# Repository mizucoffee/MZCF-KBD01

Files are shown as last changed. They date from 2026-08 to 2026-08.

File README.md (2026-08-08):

# MZCF-KBD01 V1 Rev.2

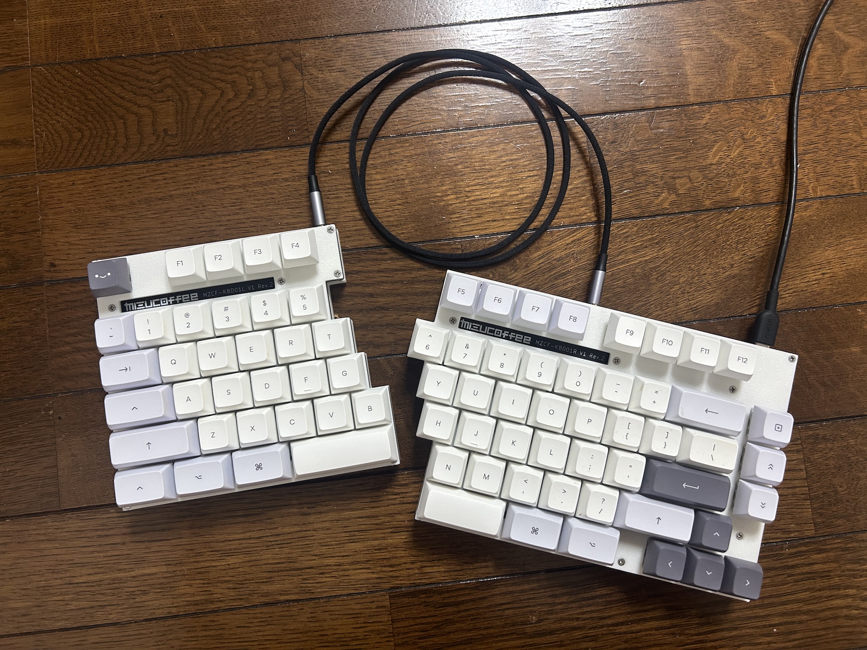
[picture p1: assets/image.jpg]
キーボード写真


RP2040-Zero を搭載した分割キーボード。レイアウトは [ergogen](https://github.com/ergogen/ergogen) で生成し、KiCad 10 で設計しています。

## 構成

| パス | 内容 |
|---|---|
| `ergogen/` | ergogen 実行用ディレクトリ(レイアウト定義 `config.yaml`・カスタムフットプリント) |
| `pcb/` | KiCad プロジェクト(左: `MZCF-KBD01L.*`、右: `MZCF-KBD01R.*`)と部品ライブラリ |
| `cad/` | Plasticity 3D モデル |
| `firmware/` | QMK ファームウェア(キーボード定義・キーマップ) |
| `docs/` | ドキュメント用画像(キーマップレイアウト図) |

## 主要部品

- **MCU**: Waveshare RP2040-Zero(各手に1個)
- **ダイオード**: 1N4148W(SOD-123、裏面実装)
- **左右接続**: XH 2.54mm 4ピンコネクタ(5V / GND / GP28 / GP29)
- **スイッチ**: Cherry MX 互換(ソルダー)

## ファームウェア(QMK)

左右どちらの半分を USB 接続してもマスターとして動作します(EE_HANDS + SPLIT_USB_DETECT)。

ホスト OS を自動判別(QMK OS Detection)し、macOS / iOS 接続時は Alt と GUI を入れ替えたレイヤー(🌐 / Opt / Cmd の並び)に自動で切り替わります。それ以外(Windows / Linux / 判別不能時)は Windows 配列(Ctrl / Win / Alt)です。

Mac レイヤー左下の 🌐/fn キーは [tzarc/qmk_modules](https://github.com/tzarc/qmk_modules) の `globe_key` モジュール(コンシューマページ `AC Next Keyboard Layout Select` 0x029D を送信)によるもので、macOS に Globe キーとして認識されます。Apple 純正 fn の全機能(fn+矢印での PgUp/Home、fn+F キーの切り替え等)は再現されない簡易実装です。

### キーマップ

Windows / Linux レイアウト

macOS / iOS レイアウト

### ファームウェア構成

- 各半分に Waveshare RP2040-Zero(USB-C 搭載)
- マトリクス: COL0–8 = GP0–GP8 / ROW0–5 = GP9–GP14(COL2ROW、左右同一配線)
- 左右間通信: GP28 の単線ハーフデュプレックス(RP2040 PIO `vendor` ドライバ)。GP29 は予備
- ハンド判定ピンなし → EE_HANDS(初回書き込み時に EEPROM へ記録)

### セットアップ(初回のみ)

QMK CLI をインストールし、qmk_firmware を取得したうえで、`firmware/` を `mzcf_kbd01` という名前で symlink します(キーボード名は symlink 名で決まります)。

```sh
brew install qmk/qmk/qmk        # または pipx install qmk
qmk setup -H ~/qmk_firmware
ln -sfn "$(pwd)/firmware" ~/qmk_firmware/keyboards/mzcf_kbd01   # リポジトリ root で実行

# コミュニティモジュール(Mac用 🌐/fn キーに使用)
git clone https://github.com/tzarc/qmk_modules.git ~/qmk_firmware/modules/tzarc
```

※ QMK External Userspace はキーマップ専用でキーボード定義を置けないため、symlink 方式にしています。キーボード定義の実体はこのリポジトリで管理されます。

### ビルド

```sh
qmk compile -kb mzcf_kbd01 -km default
# → ~/qmk_firmware/mzcf_kbd01_default.uf2
```

### 書き込み

初回(左右のハンド情報を書き込む・各半分1回だけ):

```sh
# 左手側
qmk flash -kb mzcf_kbd01 -km default -bl uf2-split-left
# 右手側
qmk flash -kb mzcf_kbd01 -km default -bl uf2-split-right
```

ブートローダへの入り方: RP2040-Zero の **BOOT** ボタンを押しながら USB を接続すると `RPI-RP2` ドライブがマウントされ、qmk が自動で書き込みます(UF2 のドラッグ&ドロップでも可)。

2回目以降:

```sh
qmk flash -kb mzcf_kbd01 -km default -bl uf2
```

ハンド情報は EEPROM(フラッシュエミュレーション)に保持されるため、通常の書き込みでは消えません。`flash_nuke.uf2` などでフラッシュを全消去した場合のみ、初回手順をやり直してください。

### 運用メモ

- USB を接続した側が自動的にマスターになります(SPLIT_USB_DETECT。接続後 2 秒ほどの判定時間があります)
- もう一方の半分は TRRS 経由で給電・通信されます
- **TRRS ケーブルの活線挿抜はしないでください**(5V が通っているため。抜き差しは USB を抜いた状態で)
- Bootmagic は無効化しています(EEPROM リセットでハンド情報が消えるのを防ぐため)。ブートローダには BOOT ボタンで入ってください

## ライブラリについて

`pcb/libs/lcsc/` のシンボル・フットプリントは LCSC / EasyEDA のデータを変換したものです。

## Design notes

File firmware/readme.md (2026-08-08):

# MZCF-KBD01

A split keyboard with an RP2040-Zero on each half, connected by a TRRS cable.
Either half can be plugged into USB (EE_HANDS + SPLIT_USB_DETECT).

* Keyboard Maintainer: [mizucoffee](https://github.com/mizucoffee)
* Hardware Supported: MZCF-KBD01 PCBs (Waveshare RP2040-Zero)
* Hardware Availability: https://github.com/mizucoffee (personal project)

Make example for this keyboard (after setting up your build environment):

    make mzcf_kbd01:default

Flashing example for this keyboard (first flash per half, to store handedness):

    qmk flash -kb mzcf_kbd01 -km default -bl uf2-split-left
    qmk flash -kb mzcf_kbd01 -km default -bl uf2-split-right

See the [build environment setup](https://docs.qmk.fm/#/getting_started_build_tools) and the [make instructions](https://docs.qmk.fm/#/getting_started_make_guide) for more information. Brand new to QMK? Start with our [Complete Newbs Guide](https://docs.qmk.fm/#/newbs).

## Bootloader

Enter the bootloader by holding the **BOOT** button on the RP2040-Zero while plugging in USB (the `RPI-RP2` drive appears).

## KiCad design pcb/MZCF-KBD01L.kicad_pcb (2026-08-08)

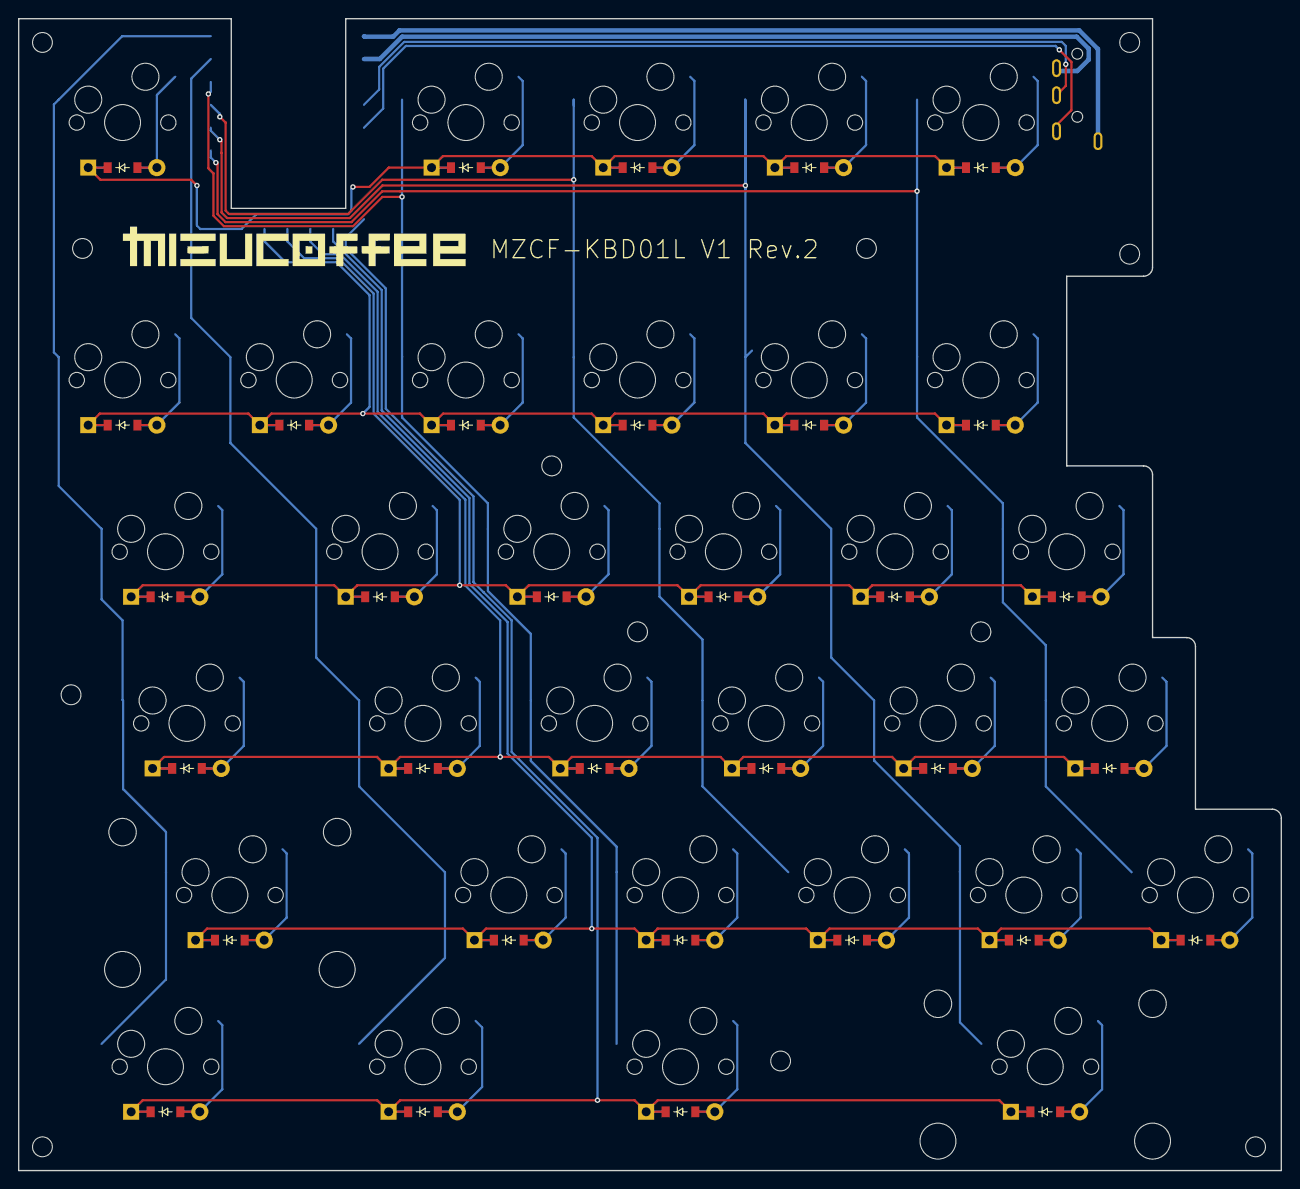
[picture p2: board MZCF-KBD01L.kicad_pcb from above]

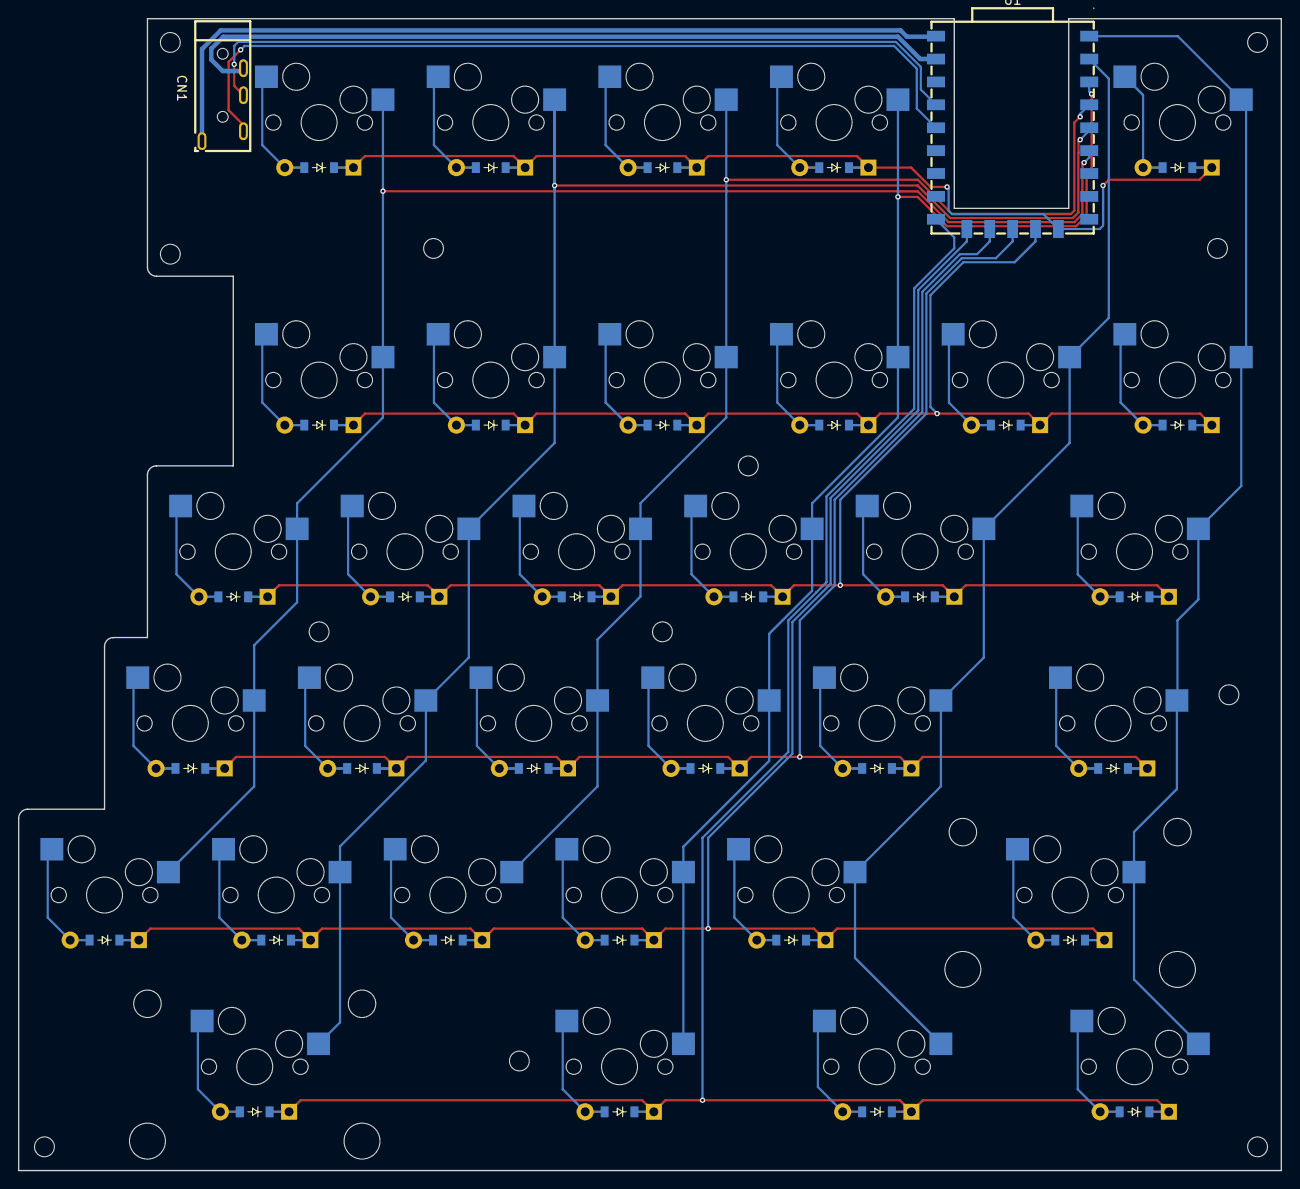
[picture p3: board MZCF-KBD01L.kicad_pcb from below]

Board: 2 copper layers, 140.1 x 127.8 mm, 82 parts (35 on the bottom side), 49 nets.

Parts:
CN1: PJ-320A_C49284721; C49284721_AUDIO-TH_PJ-320A_C49284721
D1, D2, D3, D4, D5, D6, D8, D9, D10, D11, D12, D13, D14, D15, D16, D17, D18, D19, D20, D21, D22, D23, D25, D26, D27, D28, D29, D30, D31, D32, D33, D34, D35: 1N4148W; ComboDiode
H1, H1#2, H1#3, H1#4, H1#5, H1#6, H1#7, H1#8, H1#9, H1#10, H1#11, H1#12: MountingHole_2.2mm_M2
ST1, ST2: STAB_MX
SW1, SW2, SW3, SW4, SW5, SW6, SW8, SW9, SW10, SW11, SW12, SW13, SW14, SW15, SW16, SW17, SW18, SW19, SW20, SW21, SW22, SW23, SW25, SW26, SW27, SW28, SW29, SW30, SW31, SW32, SW33, SW34, SW35: SW_Push; MX
U1: RP2040-ZERO; C5350143_COMM-SMD_RP2040-ZERO

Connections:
/COL0: SW1.1, SW2.1, SW3.1, SW4.1, SW5.1, SW6.1, U1.1 (GP0)
/COL1: SW8.1, SW9.1, SW10.1, SW11.1, SW12.1, U1.2 (GP1)
/COL2: SW13.1, SW14.1, SW15.1, SW16.1, SW17.1, SW18.1, U1.3 (GP2)
/COL3: SW19.1, SW20.1, SW21.1, SW22.1, SW23.1, U1.4 (GP3)
/COL4: SW25.1, SW26.1, SW27.1, SW28.1, SW29.1, SW30.1, U1.5 (GP4)
/COL5: SW31.1, SW32.1, SW33.1, SW34.1, SW35.1, U1.6 (GP5)
/ROW0: D1.1 (K), D13.1 (K), D19.1 (K), D25.1 (K), D31.1 (K), U1.10 (GP9)
/ROW1: D2.1 (K), D8.1 (K), D14.1 (K), D20.1 (K), D26.1 (K), D32.1 (K), U1.11 (GP10)
/ROW2: D3.1 (K), D9.1 (K), D15.1 (K), D21.1 (K), D27.1 (K), D33.1 (K), U1.12 (GP11)
/ROW3: D4.1 (K), D10.1 (K), D16.1 (K), D22.1 (K), D28.1 (K), D34.1 (K), U1.13 (GP12)
/ROW4: D5.1 (K), D11.1 (K), D17.1 (K), D23.1 (K), D29.1 (K), D35.1 (K), U1.14 (GP13)
/ROW5: D6.1 (K), D12.1 (K), D18.1 (K), D30.1 (K), U1.15 (GP14)
unnamed: D1.2 (A), SW1.2
unnamed: D2.2 (A), SW2.2
unnamed: D3.2 (A), SW3.2
unnamed: D4.2 (A), SW4.2
unnamed: D5.2 (A), SW5.2
unnamed: D6.2 (A), SW6.2
unnamed: D8.2 (A), SW8.2
unnamed: D9.2 (A), SW9.2
unnamed: D10.2 (A), SW10.2
unnamed: D11.2 (A), SW11.2
unnamed: D12.2 (A), SW12.2
unnamed: D13.2 (A), SW13.2
unnamed: D14.2 (A), SW14.2
unnamed: D15.2 (A), SW15.2
unnamed: D16.2 (A), SW16.2
unnamed: D17.2 (A), SW17.2
unnamed: D18.2 (A), SW18.2
unnamed: D19.2 (A), SW19.2
unnamed: D20.2 (A), SW20.2
unnamed: D21.2 (A), SW21.2
unnamed: D22.2 (A), SW22.2
unnamed: D23.2 (A), SW23.2
unnamed: D25.2 (A), SW25.2
unnamed: D26.2 (A), SW26.2
unnamed: D27.2 (A), SW27.2
unnamed: D28.2 (A), SW28.2
unnamed: D29.2 (A), SW29.2
unnamed: D30.2 (A), SW30.2
unnamed: D31.2 (A), SW31.2
unnamed: D32.2 (A), SW32.2
unnamed: D33.2 (A), SW33.2
unnamed: D34.2 (A), SW34.2
unnamed: D35.2 (A), SW35.2
unnamed: CN1.2, U1.23 (5V)
unnamed: CN1.5, U1.22 (GND)
unnamed: CN1.4, U1.19 (GP28)
unnamed: CN1.3, U1.20 (GP29)

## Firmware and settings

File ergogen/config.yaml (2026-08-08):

meta:
  engine: 4.1.0
  name: ansi60_split
  version: 0.36

# ANSI 80% (TKL) からナビゲーションブロックを除いた左右分割版 (80キー: スペースを 2.75u + 2.25u に分割)
# 最下段は 左: Ctrl/Super/Alt(1.5u) + Space(2.75u), 右: Space(2.25u) + Alt/Super(1.5u) + [0.75uギャップ] + ← ↓ →(1u)。
# 右手側は 65% 風に右端へ 1u 列 (Del/PgUp/PgDn と最下段の →) を持つ。シフト行の右端キーは無し。
# 最右列は → (最下段) を除いて 0.25u 右にオフセットし、本体との間に 0.25u の隙間を持つ。
# 全キーが osume marshmallow ベースキット (M2024V1) のサイズ構成で賄える。
# 分割点はタッチタイピングの運指に合わせて Esc+F1-F4|F5-F12, 5|6, T|Y, G|H, B|N。
# 1行 = 1ゾーンとして定義し、行ごとのスタッガーは anchor.shift で表現する。
# ゾーン名は l/r プレフィックスで左右を区別し、外形や PCB のフィルタ (/^l/, /^r/) に使う。
# U = 19.05mm (1u キーピッチ)。キー幅は width と、外形生成用の幅タグ (k100=1u, k125=1.25u, ...) で表現する。

units:
  # 左右の間隔 (左手ブロック右端から右手ブロック左端まで)
  splitgap: 30

points:
  key:
    spread: 1U
    padding: 1U
    width: 1U
    height: 1U
    tags: [k100]

  zones:
    # ================ 左手 ================
    # ---- F行: Esc [1uギャップ] F1 F2 F3 F4 (数字行との縦ピッチは 1.5U) ----
    lfn:
      anchor:
        shift: [0.5U, 1.5U]
      rows:
        r:
          row_net: R0
      columns:
        esc: { key.column_net: C0 }
        f1:
          key:
            spread: 2U
            column_net: C2
        f2: { key.column_net: C3 }
        f3: { key.column_net: C4 }
        f4: { key.column_net: C5 }

    # ---- 数字行: ` 1 2 3 4 5 ----
    lnum:
      anchor:
        shift: [0.5U, 0]
      rows:
        r:
          row_net: R1
      columns:
        grv: { key.column_net: C0 }
        n1: { key.column_net: C1 }
        n2: { key.column_net: C2 }
        n3: { key.column_net: C3 }
        n4: { key.column_net: C4 }
        n5: { key.column_net: C5 }

    # ---- Tab行: Tab(1.5u) Q W E R T ----
    ltab:
      anchor:
        shift: [0.75U, -1U]
      rows:
        r:
          row_net: R2
      columns:
        tab:
          key:
            width: 1.5U
            tags: [k150]
            column_net: C0
        q:
          key:
            spread: 1.25U
            column_net: C1
        w: { key.column_net: C2 }
        e: { key.column_net: C3 }
        r: { key.column_net: C4 }
        t: { key.column_net: C5 }

    # ---- ホーム行: Caps(1.75u) A S D F G ----
    lhome:
      anchor:
        shift: [0.875U, -2U]
      rows:
        r:
          row_net: R3
      columns:
        caps:
          key:
            width: 1.75U
            tags: [k175]
            column_net: C0
        a:
          key:
            spread: 1.375U
            column_net: C1
        s: { key.column_net: C2 }
        d: { key.column_net: C3 }
        f: { key.column_net: C4 }
        g: { key.column_net: C5 }

    # ---- シフト行: LShift(2.25u) Z X C V B ----
    lshift:
      anchor:
        shift: [1.125U, -3U]
      rows:
        r:
          row_net: R4
      columns:
        lsft:
          key:
            width: 2.25U
            tags: [k225]
            column_net: C0
        z:
          key:
            spread: 1.625U
            column_net: C1
        x: { key.column_net: C2 }
        c: { key.column_net: C3 }
        v: { key.column_net: C4 }
        b: { key.column_net: C5 }

    # ---- 最下段: Ctrl/Super/Alt(1.5u) Space(2.75u = 残り幅) ----
    lbot:
      anchor:
        shift: [0.75U, -4U]
      rows:
        r:
          row_net: R5
      columns:
        lctl:
          key:
            width: 1.5U
            tags: [k150]
            column_net: C0
        lgui:
          key:
            spread: 1.5U
            width: 1.5U
            tags: [k150]
            column_net: C1
        lalt:
          key:
            spread: 1.5U
            width: 1.5U
            tags: [k150]
            column_net: C2
        spc:
          key:
            spread: 2.125U
            width: 2.75U
            tags: [k275]
            column_net: C4

    # ================ 右手 ================
    # ---- F行: F5 F6 F7 F8 [0.5uギャップ] F9 F10 F11 F12 ----
    rfn:
      anchor:
        shift: [7U + splitgap, 1.5U]
      rows:
        r:
          row_net: R0
      columns:
        f5: { key.column_net: C1 }
        f6: { key.column_net: C2 }
        f7: { key.column_net: C3 }
        f8: { key.column_net: C4 }
        f9:
          key:
            spread: 1.5U
            column_net: C5
        f10: { key.column_net: C6 }
        f11: { key.column_net: C7 }
        f12: { key.column_net: C8 }

    # ---- 数字行: 6 7 8 9 0 - = Backspace(2u) Del ----
    rnum:
      anchor:
        shift: [6.5U + splitgap, 0]
      rows:
        r:
          row_net: R1
      columns:
        n6: { key.column_net: C0 }
        n7: { key.column_net: C1 }
        n8: { key.column_net: C2 }
        n9: { key.column_net: C3 }
        n0: { key.column_net: C4 }
        minus: { key.column_net: C5 }
        equal: { key.column_net: C6 }
        bksp:
          key:
            spread: 1.5U
            width: 2U
            tags: [k200]
            column_net: C7
        del:
          key:
            spread: 1.75U
            column_net: C8
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

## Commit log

2026-07-24 feat: add KiCad PCB design for MZCF-KBD01 split keyboard with ergogen config and LCSC libraries
    [MZCF-KBD01L.kicad_pcb, MZCF-KBD01L.kicad_sch, MZCF-KBD01R.kicad_pcb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]
2026-07-27 chore: add Plasticity model and ignore 3D print outputs
2026-08-01 feat: new left keyboard
    [MZCF-KBD01L.kicad_pcb, MZCF-KBD01L.kicad_sch, MZCF-KBD01R.kicad_sch]
2026-08-02 feat: add hotswap MX switches and PCB stabilizer support
    [MZCF-KBD01L.kicad_pcb, MZCF-KBD01R.kicad_pcb, MZCF-KBD01R.kicad_sch]
2026-08-02 fix(pcb): add controller cutouts and mating-edge clearance
    [MZCF-KBD01L.kicad_pcb, MZCF-KBD01R.kicad_pcb]
2026-08-08 feat: add QMK firmware for MZCF-KBD01
    [MZCF-KBD01L.kicad_pcb, MZCF-KBD01L.kicad_sch, MZCF-KBD01R.kicad_pcb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]
2026-08-08 refactor: reorganize repository layout
    - KiCad プロジェクトと部品ライブラリを pcb/ へ移動
    - Plasticity モデルを cad/ へ移動
    - keyboard.yaml を削除し ergogen/config.yaml に一本化(内容は同一)
    - fp-lib-table から実体のない MX_Hotswap.pretty 参照を削除
    - README の構成表を新レイアウトに更新
2026-08-08 fix: replace config.yaml symlink with real file
    ergogen/config.yaml は ../keyboard.yaml へのシンボリックリンクだったため、
    keyboard.yaml 削除でリンク切れになっていた。9de426f 時点の内容を実ファイルとして復元。
    [config.yaml]
2026-08-08 refactor: flatten firmware directory and move docs to root
    - firmware/mzcf_kbd01/ の1階層を解消し、キーボード定義を firmware/ 直下へ
    - レイアウト図を firmware/docs/ から docs/ へ移動
    - README の symlink 手順と画像パスを更新
